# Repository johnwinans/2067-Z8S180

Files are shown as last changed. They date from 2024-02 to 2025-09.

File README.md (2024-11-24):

# 2067-Z8S180
Z8S180 Breakout Board

- There is a YouTube playlist that discusses the [Z80-Nouveau](https://www.youtube.com/playlist?list=PL3by7evD3F52rUbThUNDYGxNpKFF1HCNT) project for which this board is an early prototype.
- There is a [Verilog/FPGA YouTube tutorial series](https://www.youtube.com/playlist?list=PL3by7evD3F52On-ws9pcdQuEL-rYbNNFB)
- [Verilog examples](https://github.com/johnwinans/Verilog-Examples) that go along with the above YouTube tutorial.
- This board plugs into the [2057-ICE40HX4K-TQ144-breakout](https://github.com/johnwinans/2057-ICE40HX4K-TQ144-breakout) board.

# Useful DOC

- [Schematic PDF](./2067-Z8S180.pdf)
- [Latest release with gerbers](https://github.com/johnwinans/2067-Z8S180/releases/latest)
- [Z80 CPU User Manual UM008011](https://www.zilog.com/docs/z80/um0080.pdf)
- [Z8S180 Manuals](https://zilog.com/index.php?Itemid=26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)
    - [Z8S180 DS0060 - Product Specification](https://www.zilog.com/docs/z180/z8s180ps.pdf)
    - [Z80180 UM0050 - User Manual](https://www.zilog.com/docs/z180/um0050.pdf)

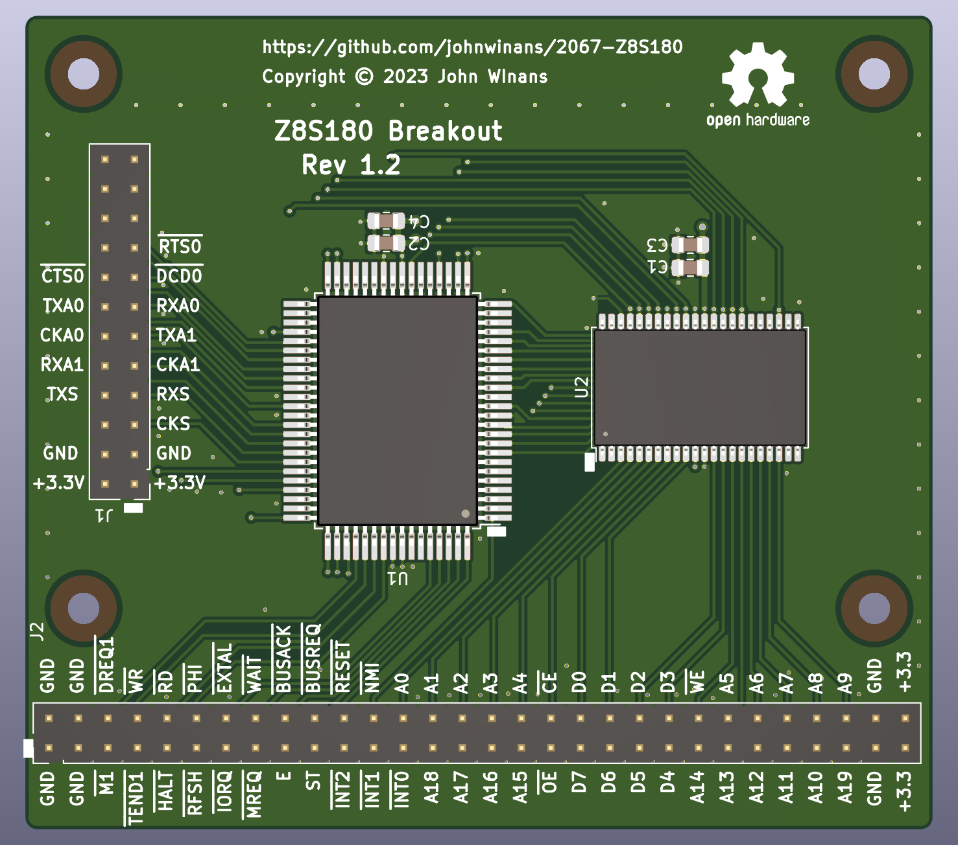
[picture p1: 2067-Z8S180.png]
PCB image


# Revision History

## 1.1 Change CPU footprint to make the pads longer
- add mounting holes
- add labels to the pins on J2

## 1.2 Thermal Relief
- reduce spoke widths
- keep polygon pours off the CPU GND pins
- Connect SRAM A20 to GND w/cuttable track

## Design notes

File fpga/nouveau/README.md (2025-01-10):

An example of booting the CPU and running code that is in multiple
RAM4k Blocks in the FPGA.

The code in the RAM block is assembled into binary and then loaded into
an FPGA block RAM by making it part of the initialization logic for an
array of bytes.

On a PI or Ubuntu system, install the Z80 assembler I used like this:

```
sudo apt install z80asm
```

This can be used to boot the Z80-Retro! boot/firmware.bin file.

The default Z8S180 internal I/O device address map is 00-3f:

CNTLA0	00
CNTLA1	01
CNTLB0	02
CNTLB1	03
STAT0	04
STAT1	05
TDR0	06
TDR1	07
RDR0	08
RDR1	09
CNTR	0a
TRDR	0b
TMDR0L	0c
TMDR0H	0d
RLDR0L	0e
RLDR0H	0f
TCR		10

ASEXT0	12
ASEXT1	13

TMDR1L	14
TMDR1H	15
RLDR1L	16
RLDR1H	17
FRC		18

ASTC0L	1a
ASTC0H	1b
ASTC1L	1c
ASTC1H	1d
CLKMUL	1e

SAR0L	20
SAR0H	21
SAR0B	22
DAR0L	23
DAR0H	24
DAR0B	25
BCR0L	26
BCR0H	27
MAR1L	28
MAR1H	29
MAR1B	2a
IAR1L	2b
IAR1H	2c
IAR1B	2d
BCR1L	2e
BCR1H	2f

DSTAT	30
DMODE	31
DCNTL	32

IL		33
ITC		34

RCR		36

CBR		38
BBR		39
CBAR	3a
OMCR	3e

ICR		3f

Note that E falls as T1 rises :-(
Consider a one-shot FSM what triggers on posedge phi when E&IORQ&RD/WR 
and allows one edge to pass and then seizes until E goes low again.

This would also work without E on just the IORQ&WR, IORQ&RD. But
in this case it might be better to latch on the second PHI edge in 
case phi T2 sneaks through.

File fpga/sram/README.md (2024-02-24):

An example of booting the CPU and running code that is in one of the 
RAM4k Blocks in the FPGA.

The code in the RAM block is assembled into binary and then loaded into
an FPGA block RAM by making it part of the initialization logic for an
array of bytes.

On a PI or Ubuntu system, install the Z80 assembler I used like this:

```
sudo apt install z80asm
```

This test includes adding a register inside the FPGA that latches any
value written to memory address 0xffff and displays it on the LEDs.

This is useful when combined with the LDIR test program running from
the FPGA memory block that padds the memory.

Observation: The only way the proper pattern can be seen on the LEDs 
is if every memory byte from 0x0200 through 0xfffe can be written and 
then read back properly... good enough for this simple test!

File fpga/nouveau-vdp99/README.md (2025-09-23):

# A Z80 Nouveau with a TI99 style VDP

Note that the IO interface of the VDP is running in the
pixel clock domain and the CPU is running in the PHI clock
domain.

[Related video discussion on YouTube.](https://youtu.be/vwotP50WOko)

The following program can be used to set the VDP regs with values
for a suitable test pattern for commit: e3811cc2d82fea9283de4cb5aa280cf6de1f5f84 
```
  0100  LD   B,08
  0102  LD   C,80
  0104  LD   D,80
  0106  LD   A,C
  0107  OUT  81,A
  0109  LD   A,D
  010A  OUT  81,A
  010C  INC  C
  010D  INC  D
  010E  DJNZ F6
  0110  NOP  
  0111  RET  
```

# Memory Map

Note that the Z8S180 has its own internal IO devices mapped to addresses 00-3F.

```
80	VDP VRAM
81	VDP registers

A8	Joystick J3
A9	Joystick J4

B0	AY-3-8910
B1	AY-3-8910

F0	GPIO input
F1	GPIO output

FE	Boot flash select disable
```

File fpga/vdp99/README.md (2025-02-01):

# A TI99-ish VDP

# Video Modes:
## M1
## M2
## M3
## text

# Writable control regs (2-byte config mode1):
```
CR0: 0 0 0 0 0 M3 0
CR1: x BLK IE M1 M2 0 SSIZ SMAG
CR2: 0 0 0 0 n n n n                    nn.nn00 0000.0000 = name base address
CR3: n n n n n n n n                    nn.nnnn nn00.0000 = color base address
CR4: 0 0 0 0 0 n n n                    nn.n000 0000.0000 = pattern base
CR5: 0 n n n n n n n                    nn.nnnn n000.0000 = sprite attribute base
CR6: 0 0 0 0 0 n n n                    nn.n000 0000.0000 = sprite pattern base
CR7: a a a a b b b b                    aaaa = text foreground, bbbb = text background & border
```

# Readable Status Register (just read the mode1 port):
```
ST:  F 5TH C S S S S S
    F = frame ended since last read
    5TH = five or more sprites on one line
    C = Coincidence/coln if two visible sprite px overlap
    SSSSS = lowest priority sprite on the horizontal line when 5TH is set
```

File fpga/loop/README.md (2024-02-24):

Simulate a small ROM that has a program in it that jumps
to itself in a loop.

There are three variations:

```
JMP .               ; endless loop
```

```
LD A,0
OUT0 (0x36),A       ; shut off automatic refresh feature
JMP .               ; endless loop
```

```
LD A,0
OUT0 (0x36),A       ; shut off automatic refresh feature
OUT0 (0x32),A       ; shut off the wait-state generator
JMP .               ; endless loop
```

Note that this uses the Z8S180 instruction `OUT0` because the regular Z80 `OUT` instruction.
See the following from the Z80 CPU User Manual:

OUT (n),A

The operand n is placed on the bottom half (A0 through A7) of the address bus to select
the I/O device at one of 256 possible ports. The contents of the Accumulator (Register A)
also appear on the top half (A8 through A15) of the address bus at this time. Then the 
byte contained in the Accumulator is placed on the data bus and written to the selected 
peripheral device.

The manual for the Z8S180 states that when writing to the I/O ports that are internal 
to the SOC, you must make sure that A8-A15 are zero!

The *corret* way to write to the I/O ports in the S180 SOC is to use the `OUT0` instruction!

Side note:  Since I am writing the value 0x00 to the output port, it just so happens
that the `OUT` instruction would, in fact, work OK in this specific case.  But ONLY
because I am outputting a zero to the port!

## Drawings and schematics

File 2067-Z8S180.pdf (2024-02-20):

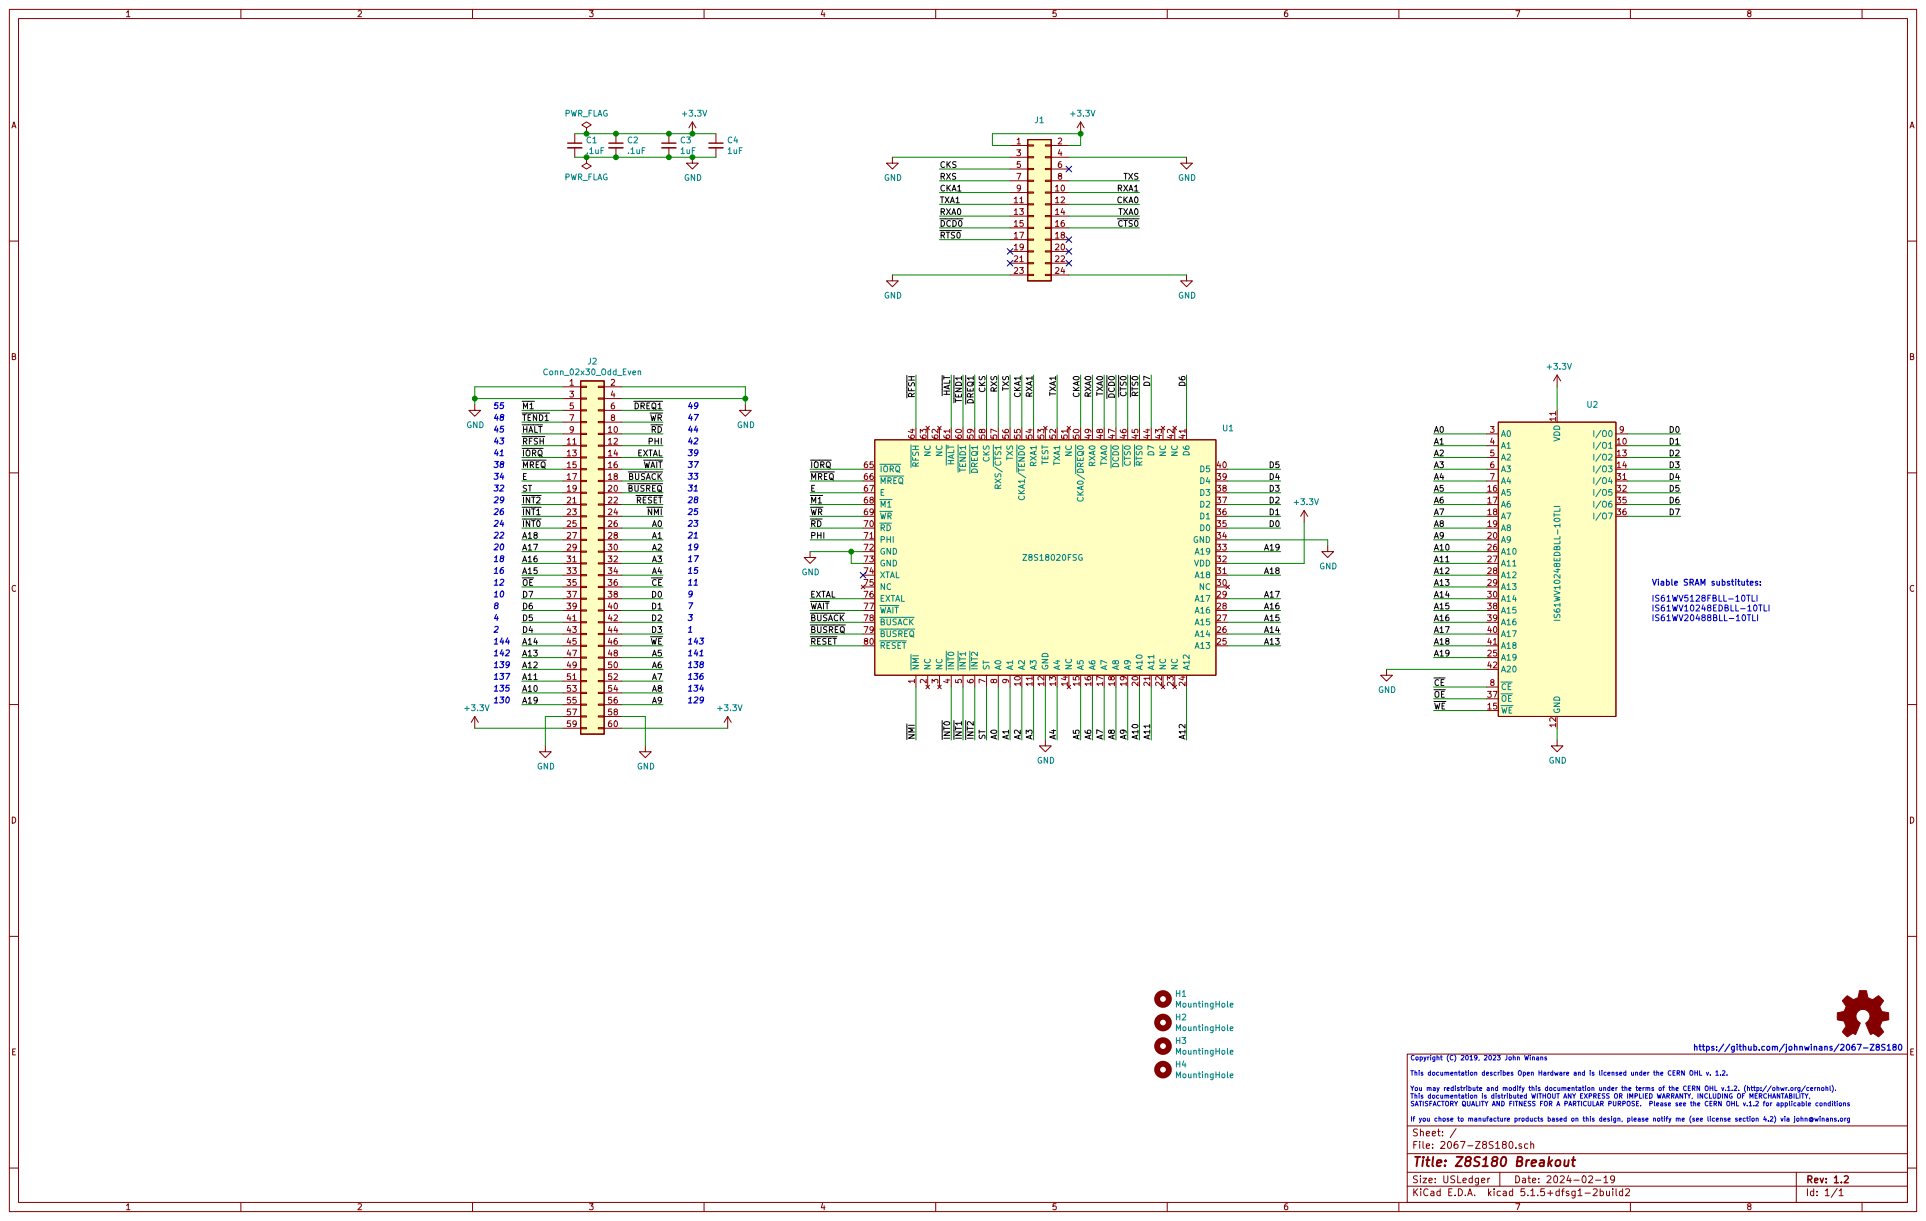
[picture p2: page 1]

6 TEND1 60 HALT 61 NC 62 NC 63 RFSH 64
BUSACK WAIT EXTAL PHI RDWR M1 E

5 CKA0/DREQ0 50 NC 51 TXA1 52 TEST 53 RXA1 54 CKA1/TEND0 55 TXS 56 RXS/CTS1 57 CKS 58 DREQ1 59 INT2

7 RD 70 PHI 71 GND 72 GND 73 XTAL 74 NC 75 EXTAL 76 WAIT 77 BUSACK 78 BUSREQ 79 A0

https://github.com/johnwinans/2067-Z8S180 Copyright (C) 2019, 2023 John Winans This documentation describes Open Hardware and is licensed under the CERN OHL v. 1.2. You may redistribute and modify this documentation under the terms of the CERN OHL v.1.2. (http://ohwr.org/cernohl). This documentation is distributed WITHOUT ANY EXPRESS OR IMPLIED WARRANTY, INCLUDING OF MERCHANTABILITY, SATISFACTORY QUALITY AND FITNESS FOR A PARTICULAR PURPOSE. Please see the CERN OHL v.1.2 for applicable conditions
E Date: 2024-02-19 KiCad E.D.A. kicad 5.1.5+dfsg1-2build2

If you chose to manufacture products based on this design, please notify me (see license section 4.2) via john@winans.org
Id: 1/1 Title: Z8S180 Breakout File: 2067-Z8S180.sch Sheet: /

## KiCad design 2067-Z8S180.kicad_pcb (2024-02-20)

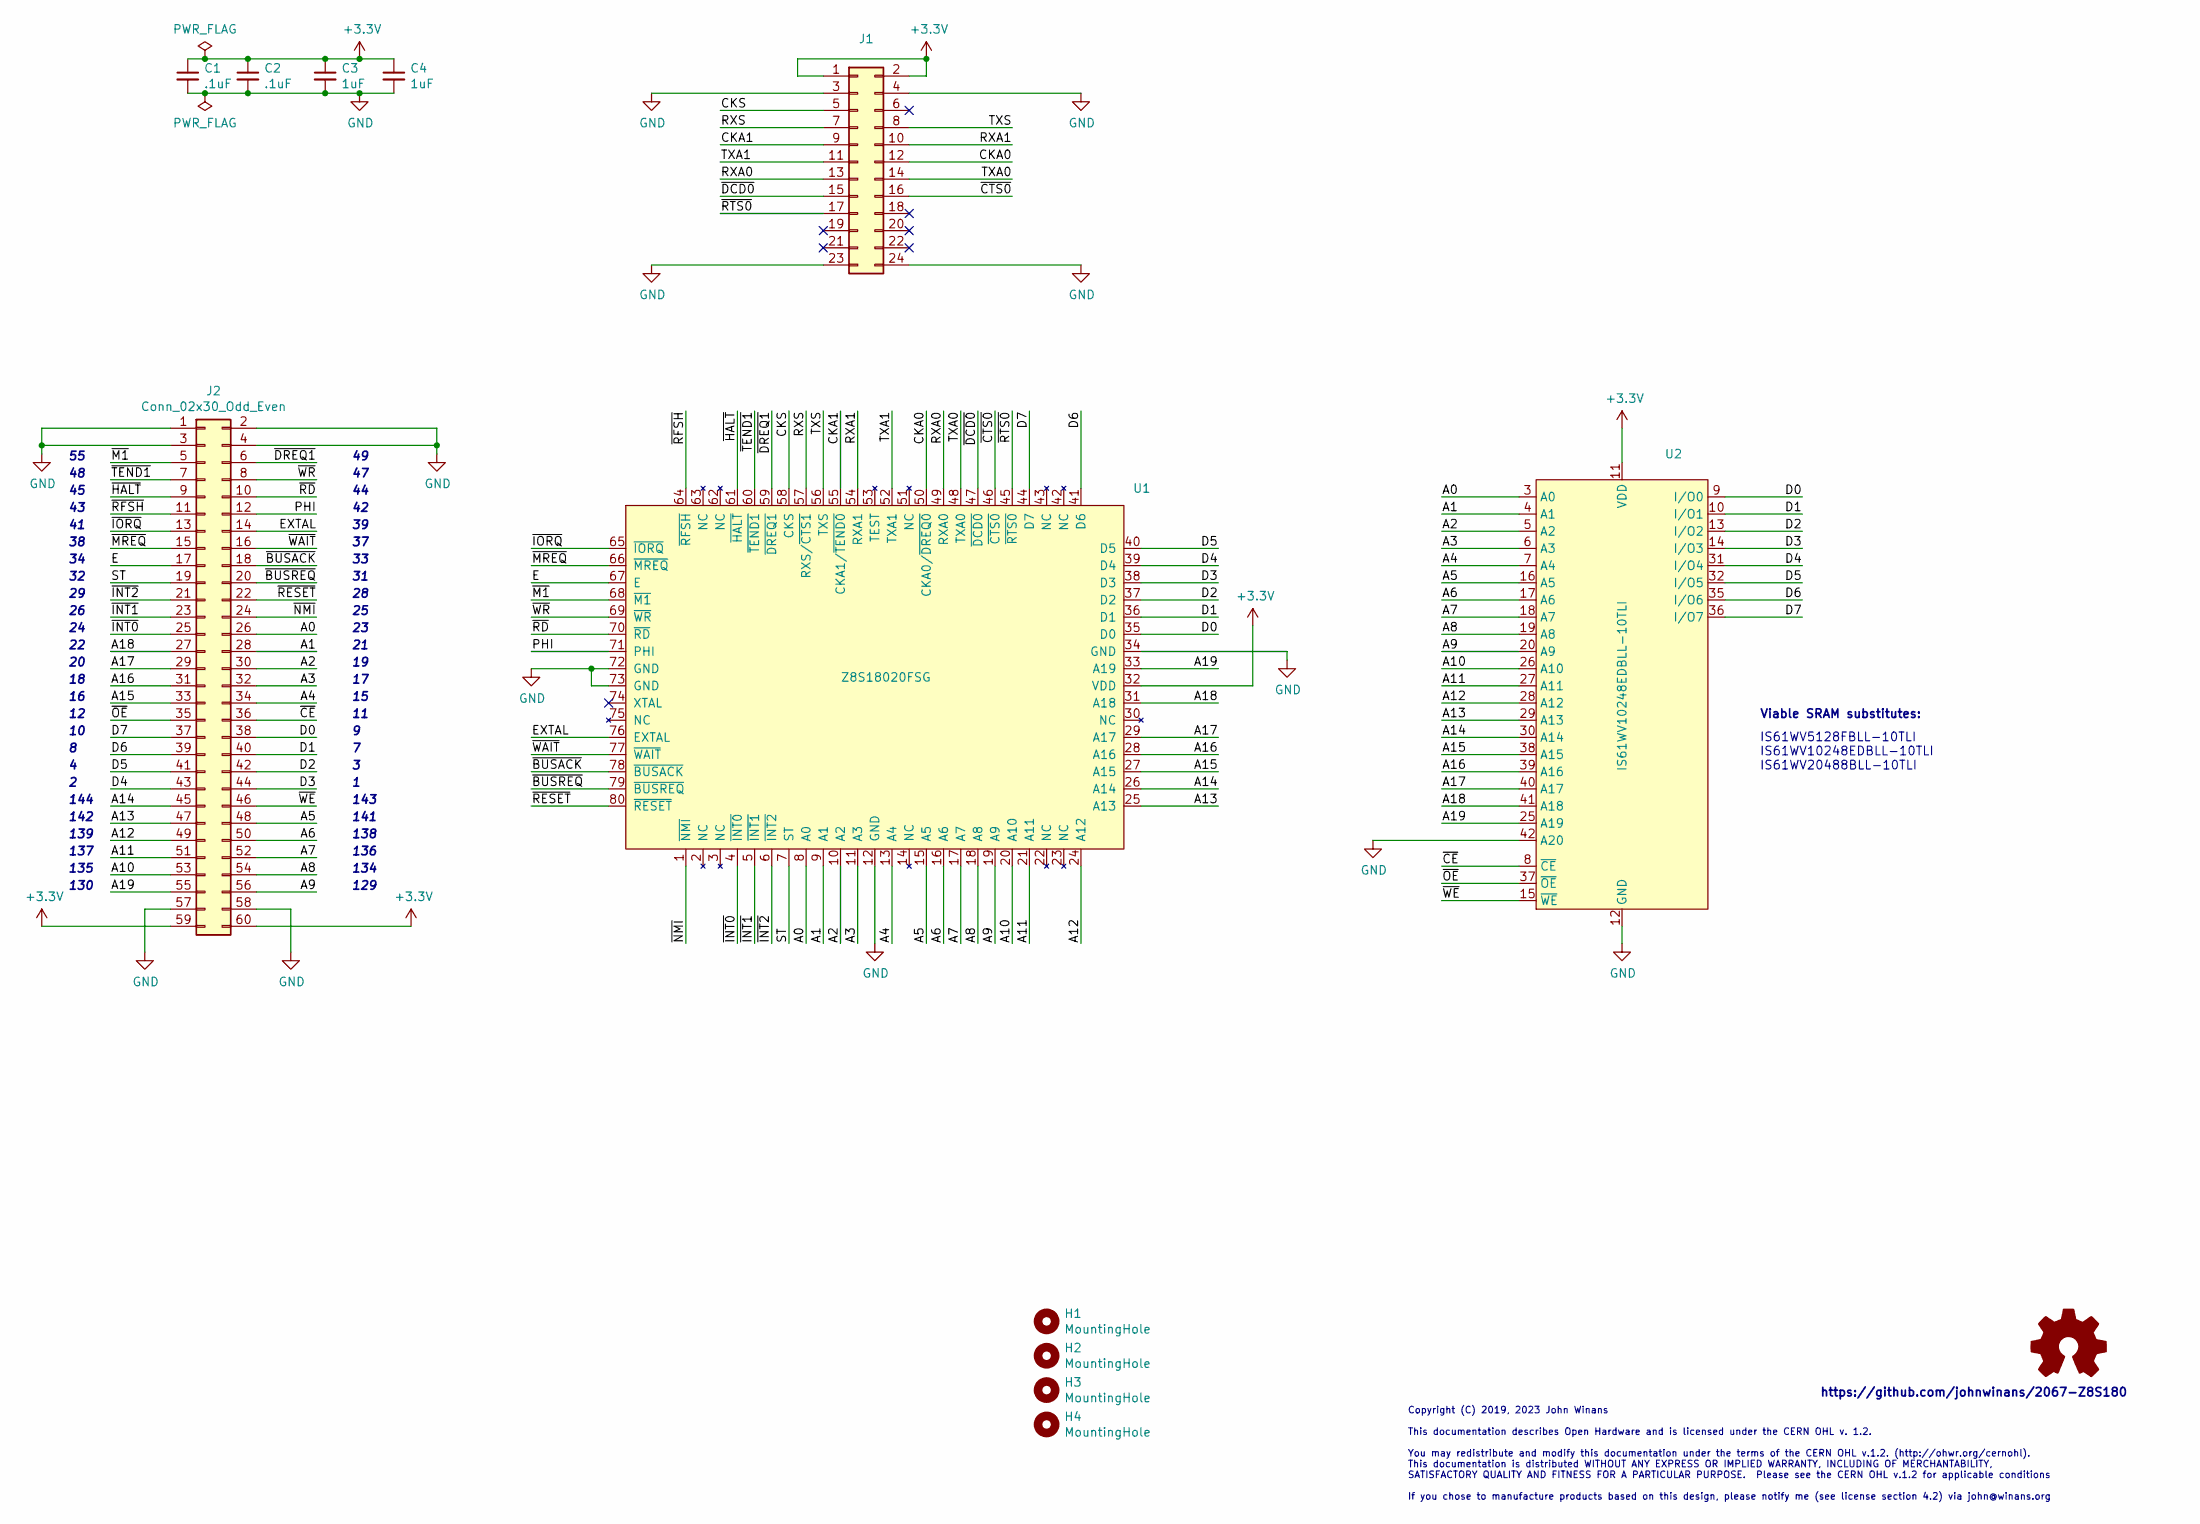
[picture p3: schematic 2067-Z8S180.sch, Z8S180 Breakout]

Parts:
C1, C2: .1uF; C_0805_2012Metric_Pad1.15x1.40mm_HandSolder
C3, C4: 1uF; C_0805_2012Metric_Pad1.15x1.40mm_HandSolder
H1, H2, H3, H4: MountingHole; MountingHole_2.7mm_M2.5
J1: Conn_02x12_Odd_Even; PinHeader_2x12_P2.54mm_Vertical
J2: Conn_02x30_Odd_Even; PinHeader_2x30_P2.54mm_Vertical
LOGO1: Logo_Open_Hardware_Small; OSHW-Logo2_9.8x8mm_SilkScreen
U1: Z8S18020FSG; PQFP-80_14x20mm_P0.8mm
U2: IS61WV10248EDBLL-10TLI; TSOP-II-44_10.16x18.41mm_P0.8mm

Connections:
+3V3: C1.1, C2.1, C3.1, C4.1, J1.1, J1.2, J2.59, J2.60, U1.32 (VDD), U2.11 (VDD), U2.33 (VDD)
/A0: J2.26, U1.8 (A0), U2.3 (A0)
/A1: J2.28, U1.9 (A1), U2.4 (A1)
/A2: J2.30, U1.10 (A2), U2.5 (A2)
/A3: J2.32, U1.11 (A3), U2.6 (A3)
/A4: J2.34, U1.13 (A4), U2.7 (A4)
/A5: J2.48, U1.15 (A5), U2.16 (A5)
/A6: J2.50, U1.16 (A6), U2.17 (A6)
/A7: J2.52, U1.17 (A7), U2.18 (A7)
/A8: J2.54, U1.18 (A8), U2.19 (A8)
/A9: J2.56, U1.19 (A9), U2.20 (A9)
/A10: J2.53, U1.20 (A10), U2.26 (A10)
/A11: J2.51, U1.21 (A11), U2.27 (A11)
/A12: J2.49, U1.24 (A12), U2.28 (A12)
/A13: J2.47, U1.25 (A13), U2.29 (A13)
/A14: J2.45, U1.26 (A14), U2.30 (A14)
/A15: J2.33, U1.27 (A15), U2.38 (A15)
/A16: J2.31, U1.28 (A16), U2.39 (A16)
/A17: J2.29, U1.29 (A17), U2.40 (A17)
/A18: J2.27, U1.31 (A18), U2.41 (A18)
/A19: J2.55, U1.33 (A19), U2.25 (A19)
/CKA0: J1.12, U1.50 (CKA0/~DREQ0)
/CKA1: J1.9, U1.55 (CKA1/~TEND0)
/CKS: J1.5, U1.58 (CKS)
/D0: J2.38, U1.35 (D0), U2.9 (I/O0)
/D1: J2.40, U1.36 (D1), U2.10 (I/O1)
/D2: J2.42, U1.37 (D2), U2.13 (I/O2)
/D3: J2.44, U1.38 (D3), U2.14 (I/O3)
/D4: J2.43, U1.39 (D4), U2.31 (I/O4)
/D5: J2.41, U1.40 (D5), U2.32 (I/O5)
/D6: J2.39, U1.41 (D6), U2.35 (I/O6)
/D7: J2.37, U1.44 (D7), U2.36 (I/O7)
/E: J2.17, U1.67 (E)
/EXTAL: J2.14, U1.76 (EXTAL)
/PHI: J2.12, U1.71 (PHI)
/RXA0: J1.13, U1.49 (RXA0)
/RXA1: J1.10, U1.54 (RXA1)
/RXS: J1.7, U1.57 (RXS/~CTS1)
/ST: J2.19, U1.7 (ST)
/TXA0: J1.14, U1.48 (TXA0)
/TXA1: J1.11, U1.52 (TXA1)
/TXS: J1.8, U1.56 (TXS)
/~BUSACK: J2.18, U1.78 (~BUSACK)
/~BUSREQ: J2.20, U1.79 (~BUSREQ)
/~CE: J2.36, U2.8 (~CE)
/~CTS0: J1.16, U1.46 (~CTS0)
/~DCD0: J1.15, U1.47 (~DCD0)
/~DREQ1: J2.6, U1.59 (~DREQ1)
/~HALT: J2.9, U1.61 (~HALT)
/~INT0: J2.25, U1.4 (~INT0)
/~INT1: J2.23, U1.5 (~INT1)
/~INT2: J2.21, U1.6 (~INT2)
/~IORQ: J2.13, U1.65 (~IORQ)
/~M1: J2.5, U1.68 (~M1)
/~MREQ: J2.15, U1.66 (~MREQ)
/~NMI: J2.24, U1.1 (~NMI)
/~OE: J2.35, U2.37 (~OE)
/~RD: J2.10, U1.70 (~RD)
/~RESET: J2.22, U1.80 (~RESET)
/~RFSH: J2.11, U1.64 (~RFSH)
/~RTS0: J1.17, U1.45 (~RTS0)
/~TEND1: J2.7, U1.60 (~TEND1)
/~WAIT: J2.16, U1.77 (~WAIT)
/~WE: J2.46, U2.15 (~WE)
/~WR: J2.8, U1.69 (~WR)
GND: C1.2, C2.2, C3.2, C4.2, J1.3, J1.4, J1.23, J1.24, J2.1, J2.2, J2.3, J2.4, J2.57, J2.58, U1.12 (GND), U1.34 (GND), U1.72 (GND), U1.73 (GND), U2.12 (GND), U2.34 (GND), U2.42 (A20)

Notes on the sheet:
144
142
139
137
135
130
129
134
136
138
141
143
IS61WV5128FBLL-10TLI IS61WV10248EDBLL-10TLI IS61WV20488BLL-10TLI
Viable SRAM substitutes:
Copyright (C) 2019, 2023 John Winans This documentation describes Open Hardware and is licensed under the CERN OHL v. 1.2. You may redistribute and modify this documentation under the terms of the CERN OHL v.1.2. (http://ohwr.org/cernohl). This documentation is distributed WITHOUT ANY EXPRESS OR IM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
https://github.com/johnwinans/2067-Z8S180

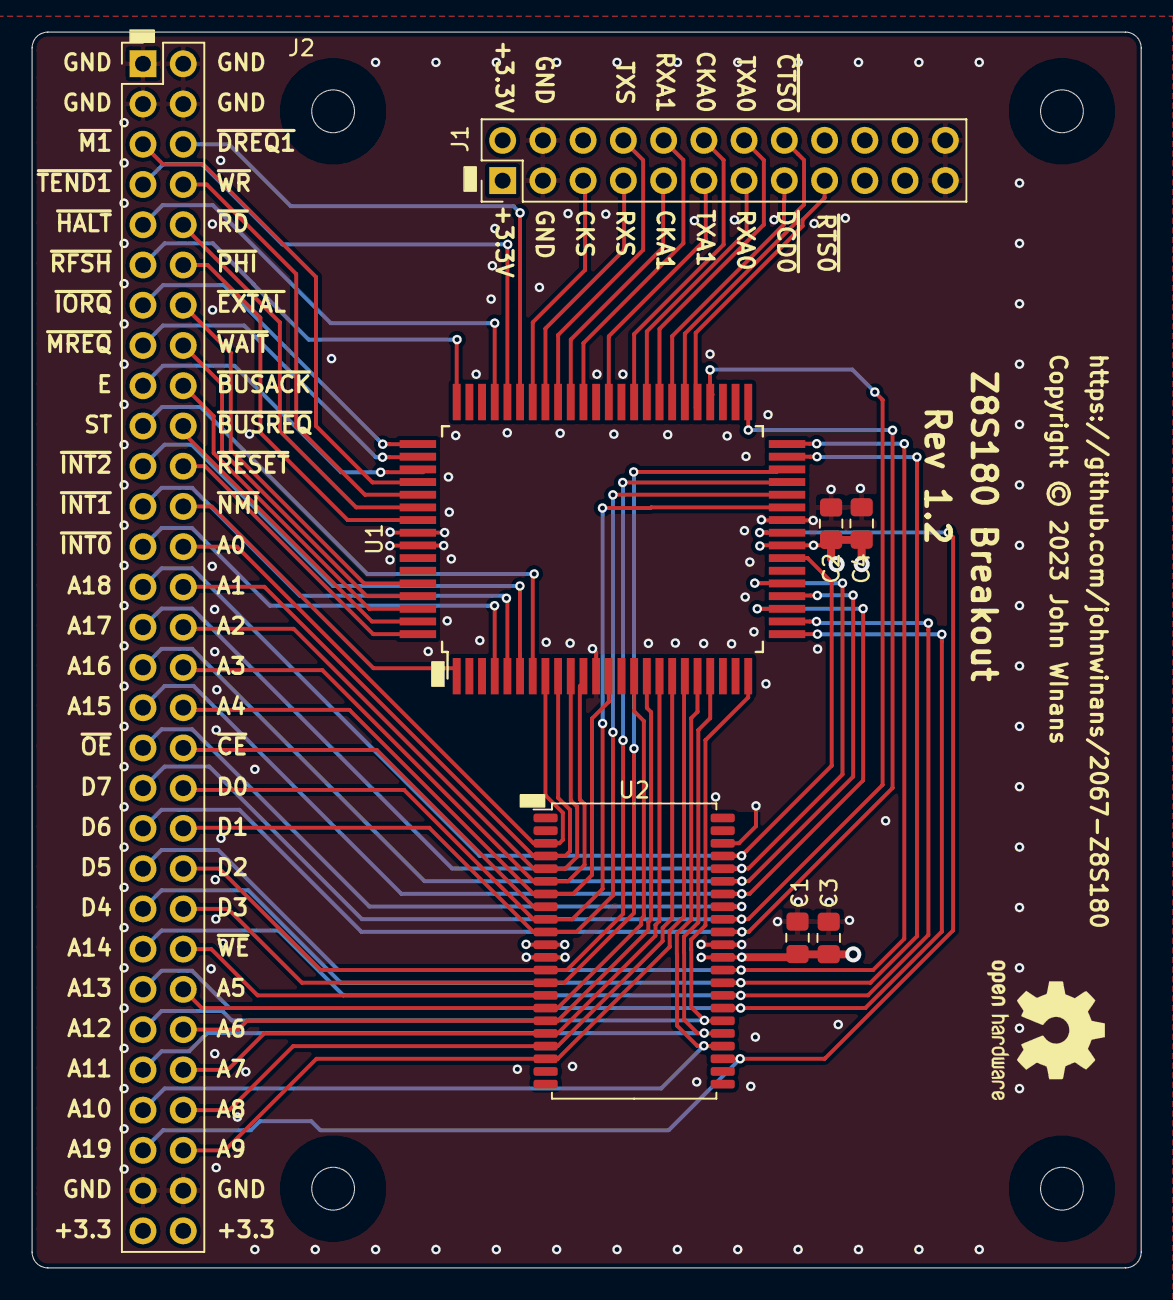
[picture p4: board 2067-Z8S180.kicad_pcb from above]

Board: 4 copper layers, 70.0 x 78.0 mm, 13 parts (0 on the bottom side), 66 nets.

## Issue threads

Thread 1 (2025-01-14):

Swap A9 with WE

johnwinans, 2025-01-14:
A9 is connected to a limited-use pin (129) on the FPGA.  When using PLL2, pin 129 can ONLY be an output mode pin.

Connecting 129 to the WE signal and then connecting pin 143 to A9 would "fix" this problem.

Note that I am not inclined to make this fix since this was only supposed to be a test prototype board.  I note it here so that the same mistake is not made when developing the next-generation design.

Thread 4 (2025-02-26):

Documentation for the nouveau-vdp99 project

dennowiggle, 2025-02-26:
In the nouveau-vdp99 directory [readme](https://github.com/johnwinans/2067-Z8S180/blob/main/fpga/nouveau-vdp99/README.md) the referenced link to the video doesn't work.

Would it be possible to share the  6-bit VGA DAC wiring diagram in the repository to help understand how to build / interpret it.

Thanks.

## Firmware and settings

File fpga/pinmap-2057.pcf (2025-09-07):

set_io -nowarn -pullup yes  a[0]        23
set_io -nowarn -pullup yes  a[1]        21
set_io -nowarn -pullup yes  a[2]        19
set_io -nowarn -pullup yes  a[3]        17
set_io -nowarn -pullup yes  a[4]        15
set_io -nowarn -pullup yes  a[5]        141
set_io -nowarn -pullup yes  a[6]        138
set_io -nowarn -pullup yes  a[7]        136
set_io -nowarn -pullup yes  a[8]        134
set_io -nowarn -pullup yes  a[9]        129     # may NOT be used as an input when using PLL 2
set_io -nowarn -pullup yes  a[10]       135
set_io -nowarn -pullup yes  a[11]       137
set_io -nowarn -pullup yes  a[12]       139
set_io -nowarn -pullup yes  a[13]       142
set_io -nowarn -pullup yes  a[14]       144
set_io -nowarn -pullup yes  a[15]       16
set_io -nowarn -pullup yes  a[16]       18
set_io -nowarn -pullup yes  a[17]       20
set_io -nowarn -pullup yes  a[18]       22
set_io -nowarn -pullup yes  a[19]       130

set_io -nowarn -pullup yes  d[0]        9
set_io -nowarn -pullup yes  d[1]        7
set_io -nowarn -pullup yes  d[2]        3
set_io -nowarn -pullup yes  d[3]        1
set_io -nowarn -pullup yes  d[4]        2
set_io -nowarn -pullup yes  d[5]        4
set_io -nowarn -pullup yes  d[6]        8
set_io -nowarn -pullup yes  d[7]        10

set_io -nowarn              busack_n    33
set_io -nowarn -pullup yes  busreq_n    31
set_io -nowarn -pullup yes  dreq1_n     49      # may NOT be used as an input when using PLL 1
set_io -nowarn              e           34
set_io -nowarn              extal       39
set_io -nowarn              halt_n      45

set_io -nowarn -pullup yes  int_n[0]    24
set_io -nowarn -pullup yes  int_n[1]    26
set_io -nowarn -pullup yes  int_n[2]    29
set_io -nowarn -pullup yes  nmi_n       25

set_io -nowarn -pullup yes  mreq_n      38
set_io -nowarn -pullup yes  iorq_n      41
set_io -nowarn -pullup yes  rd_n        44
set_io -nowarn -pullup yes  wr_n        47

set_io -nowarn              m1_n        55
set_io -nowarn              phi         42
set_io -nowarn              rfsh_n      43
set_io -nowarn              st          32
set_io -nowarn              tend1_n     48
set_io -nowarn -pullup yes  wait_n      37

set_io -nowarn              reset_n     28

set_io -nowarn              we_n        143
set_io -nowarn              oe_n        12
set_io -nowarn              ce_n        11

set_io -nowarn              hwclk       52

set_io -nowarn              led[0]      118
set_io -nowarn              led[1]      116
set_io -nowarn              led[2]      115
set_io -nowarn              led[3]      114
set_io -nowarn              led[4]      113
set_io -nowarn              led[5]      112
set_io -nowarn              led[6]      110
set_io -nowarn              led[7]      107

set_io -nowarn -pullup yes  s1_n        102
set_io -nowarn -pullup yes  s2_n        105


# A bunch of pins on the bottom for test-points
set_io -nowarn              tp[0]       56
set_io -nowarn              tp[1]       61
set_io -nowarn              tp[2]       63
set_io -nowarn              tp[3]       73
set_io -nowarn              tp[4]       75
set_io -nowarn              tp[5]       78
set_io -nowarn              tp[6]       80
set_io -nowarn              tp[7]       82
set_io -nowarn              tp[8]       84
set_io -nowarn              tp[9]       87
set_io -nowarn              tp[10]      90
set_io -nowarn              tp[11]      93
set_io -nowarn              tp[12]      95
set_io -nowarn              tp[13]      97
set_io -nowarn              tp[14]      99
set_io -nowarn              tp[15]      101

# built-in SD card pins
set_io -nowarn              sd_mosi     119
set_io -nowarn              sd_clk      124
set_io -nowarn              sd_ssel_n   117

set_io -nowarn -pullup yes  sd_miso     121
set_io -nowarn -pullup yes  sd_det      125

# VGA interface pins                            DAC resistor values
set_io -nowarn              vga_red[0]     120  # 1K
set_io -nowarn              vga_red[1]     98   # 470
set_io -nowarn              vga_grn[0]     122  # 1K
set_io -nowarn              vga_grn[1]     96   # 470
set_io -nowarn              vga_blu[0]     128  # 1K
set_io -nowarn              vga_blu[1]     94   # 470

set_io -nowarn              vga_hsync   104     # 100
set_io -nowarn              vga_vsync   106     # 100

set_io -nowarn -pullup yes	joy1_up		74
set_io -nowarn -pullup yes	joy1_dn		64
set_io -nowarn -pullup yes	joy1_lt		60
set_io -nowarn -pullup yes	joy1_rt		62
set_io -nowarn -pullup yes	joy1_fire	76
set_io -nowarn -pullup yes	joy1_btn2	79

set_io -nowarn				aout[0]		91
set_io -nowarn				aout[1]		88
set_io -nowarn				aout[2]		85

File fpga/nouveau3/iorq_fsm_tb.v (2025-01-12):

//**************************************************************************
//
//    Copyright (C) 2025  John Winans
//
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
//**************************************************************************

// don't forget this!  Else can have trouble with 0-delay rise times after phi!
`timescale 1ns/1ps  // time units & precision 


module tb ();

    reg     phi = 1;
    reg     iorq = 0;
    wire    iorq_tick;
 
    iorq_fsm uut (.phi(phi), .iorq(iorq), .iorq_tick(iorq_tick) );

    always #25 phi = ~phi;

    reg t1 = 0;     // use for refernce when viewing waveform

    initial begin
        $dumpfile("iorq_fsm_tb.vcd");
        $dumpvars;
        
        #(6*25);         // skip a machine cycle

        // An external t1-t2-tw-t3 IO cycle
        // IOC=1 (default)
       
        // READ cycle IOC=1
        // earliest (worst) case IORQ edge is 0ns after t1 falling
        t1=1;
        #(25*2);
        t1=0;
        #1;         // worse than worse, we miss t2 rising setup on iorq
        iorq = 1;   // be careful of order of operations when this coinsides with phi rising edge!
        #(3*25*2-1);
        //#(3*25*2);
        iorq = 0; // latest (worst) case iorq falling edge is coincident with the next t1 rising

        t1=1;       // skip to make waveform easier to see
        #(2*25);
        t1=0;
        #(4*25);

        // READ cycle IOC=1
        // latest case IORQ edge is 25ns after t1 falling edge
        t1=1;
        #(25*2);
        t1=0;
        iorq = 1;   // be careful of order of operations when this coinsides with phi rising edge!
        #(2*25*2+25);
        iorq = 0;   // earliest case iorq edge is 0ns after t3 falling
        #25;

        t1=1;       // skip to make waveform easier to see
        #(2*25);
        t1=0;
        #(4*25);


        // WRITE cycle IOC=1
        // earliest IORQ edge is 0ns after t2 rise

        t1=1;
        #(2*25);
        t1=0;
        #1;
        iorq = 1;       // earliest IORQ edge immediately after t2 rise
        #(2*25*2+25-1);
        iorq = 0;       // latest IORQ edge 25ns after t3 fall
        #25;

        t1=1;       // skip to make waveform easier to see
        #(2*25);
        t1=0;
        #(4*25);

        // WRITE cycle IOC=1
        // latest IORQ edge is 25ns after t2 rise

        t1=1;
        #(2*25);
        t1=0;
        #25;
        iorq = 1;       // latest IORQ edge immediately after t2 fall
        #(2*25*2);
        iorq = 0;       // earliest IORQ edge 0ns after t3 fall
        #25;



        // What happens if we trigger on an internal t1-t2-t3 IO cycle?

        t1=1;       // skip to make waveform easier to see
        #(2*25);
        t1=0;
        #(4*25);

        // internal WRITE cycle (same as external without tw)
        // latest IORQ edge is 25ns after t2 rise.
        // This will demonstrate the iorq_tick rising with t3 and then ending early.

        // Adding an address restriction on iorq_sync.iorq to prevent it from starting
        // in the first place can clean this up.

        t1=1;
        #(2*25);
        t1=0;
        #1;
        iorq = 1;       // earliest IORQ edge immediately after t2 rise
        #(2*25*1-1);
        #25;            // t3 high
        iorq = 0;       // earliest IORQ edge 0ns after t3 fall  (coinside with t1 rise)
        #25;



        t1=1;       // skip to make waveform easier to see
        #(2*25);
        t1=0;
        #(4*25);


        $finish;
    end

endmodule

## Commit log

2023-06-17 Rev 1 import
    [2067-Z8S180-B_Cu.gbl, 2067-Z8S180-B_Mask.gbs, 2067-Z8S180-B_Paste.gbp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]
2023-06-17 Add schematic pdf
2023-12-10 Fix CPU footprint, M1/DREQ, and mounting holes
    [2067-Z8S180-B_Cu.gbl, 2067-Z8S180-B_Mask.gbs, 2067-Z8S180-B_Paste.gbp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]
2023-12-10 Update schematic pdf
2023-12-11 Update revision date
    [2067-Z8S180.sch]
2023-12-13 Widen board & add J2 labels
    [2067-Z8S180-B_Cu.gbl, 2067-Z8S180-B_Mask.gbs, 2067-Z8S180-B_Paste.gbp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]
2023-12-13 Add links to playlist & 2057 FPGA board
2024-02-17 Add FPGA pin number reference
    [2067-Z8S180.sch]
2024-02-17 Add reset & NOP tester
    [pinmap-2057.pcf]
2024-02-17 Add missing bits Speed up the clock
    [pinmap-2057.pcf]
2024-02-18 Add FPGA pin numbers for reference
2024-02-20 Thermal relief, SRAM A20
    [2067-Z8S180-B_Cu.gbl, 2067-Z8S180-B_Mask.gbs, 2067-Z8S180-B_Paste.gbp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]
2025-01-14 Note problematic PLL pins
    [pinmap-2057.pcf]
2025-01-18 Add VDP_LIBV in case it becomes useful
2025-02-04 test case writes all 8 VDP config regs
2025-02-08 Cleanup test case with sane timing values
2025-02-09 Simplify sync, test @ worst case timing
2025-02-09 rethink rd/wr_tick, use last_pixel for irq, send frame flag to dout
2025-02-09 86 the ioreq_rd/wr_vdp_ticks, extend test to a full video frame
2025-02-15 Add DMA access to the VRAM for reading
2025-02-20 stat reg report end of frame, not IRQ pin state
2025-02-22 change wire to reg as appropriate
2025-02-23 Resistor DAC values for VGA color bits
2025-03-02 Run simulation into second frame
2025-03-02 Use only one VRAM read cycle when request DMA
2025-07-01 Add a dma+read conflict case
2025-09-05 Add VDP IRQ status to port A8 (a'la Retro!)
2025-09-09 Added ay_adc & pwm
2025-09-09 reduce max pwm period to 111
2025-09-10 Stub in code/comment to OR the three PWMs into one output bit
2025-10-04 Run VGA signals through sync latch to compensate for prio encoders

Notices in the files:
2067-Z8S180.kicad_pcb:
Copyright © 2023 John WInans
